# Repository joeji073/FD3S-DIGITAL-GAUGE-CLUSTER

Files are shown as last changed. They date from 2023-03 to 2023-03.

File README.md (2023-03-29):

# FD3S-DIGITAL-GAUGE-CLUSTER

Overview:
I originally started this digital gauge cluster project for my FD3S RX7 since I needed a way of keeping an eye on engine vitals, but didn't want to add gauges pods all over the dashboard. The project actually started as a single external LCD project but eventually turned into a full custom gauge cluster that tried to keep the OEM design language. 

While I'm happy where the gauge cluster currently is, there are still a lot of things that need to be finished. I taught myself how to code by watching Youtube videos and searching the internet so I don't have enough skill and knowledge to finish this. I don't want this project to be wasted and I think with the help of more knowledgeable people, this gauge cluster could become something really nice. 

With that said, I don't want to see this project commercialized or sold for profit. I would like to keep this gauge cluster project free for anyone who would like to make one of their own.

Notes:
1. For those that are expecting to download the files, buy the parts and put it together in a day, it's not even close. Almost all of the parts I used are obsolete and I don't want to spend the time to find alternate solutions.
2. Keep in mind that I've never taken a class on coding/PCB design. What you're going to see is ugly but it works as a proof of concept. I did the work of proving that yes, it's physically possible to fit five LCD screens behind the bezel. The code is literally consists of basic functions that a 10 year old could probably re-write better in a few hours. I uploaded the files not as a way for people to replicate the same thing I have but instead to spark new ideas, whether it's with different hardware or software. I've looked into the LVGL library and it looks like a better option than the FTDI EVE based displays.
3. I'm not going to provide the gauge background jpeg's since they aren't hard to replicate and I'd like to see original designs.

BOM:
1. 3X New Haven Display 3.5" LCD ---- NHD-3.5-320240FT-CSXN-CTP ---- obsolete
2. 2X New Haven Display 7.0" ---- NHD-7.0-800480FT-CSXN-CTP ---- obsolete
3. 5X Teensy 3.5 ---- out of stock, not recommended for new designs

Helpful Links:

https://github.com/FT81xMania/GD23ZUTX

https://excamera.com/files/gd2book_v0.pdf

https://www.ftdichip.com/old2020/Products/Modules/EVE2Modules.html

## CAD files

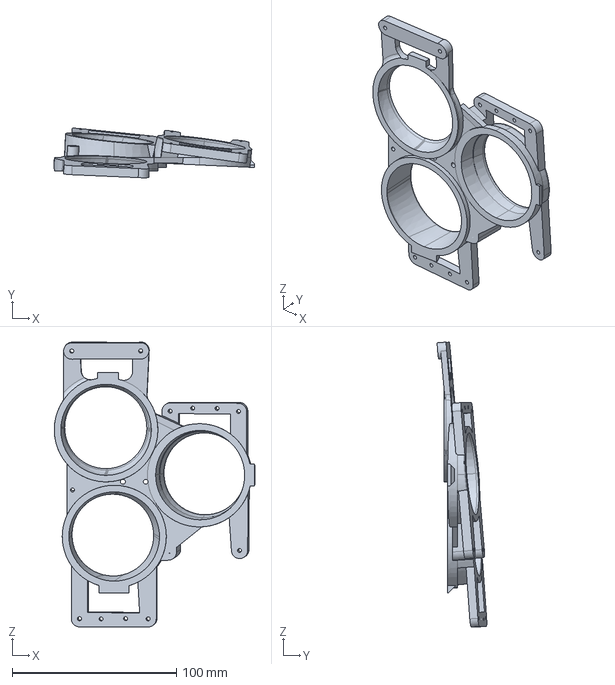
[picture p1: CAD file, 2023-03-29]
triple_gauge.stp
122.1 x 30.2 x 173.5 mm

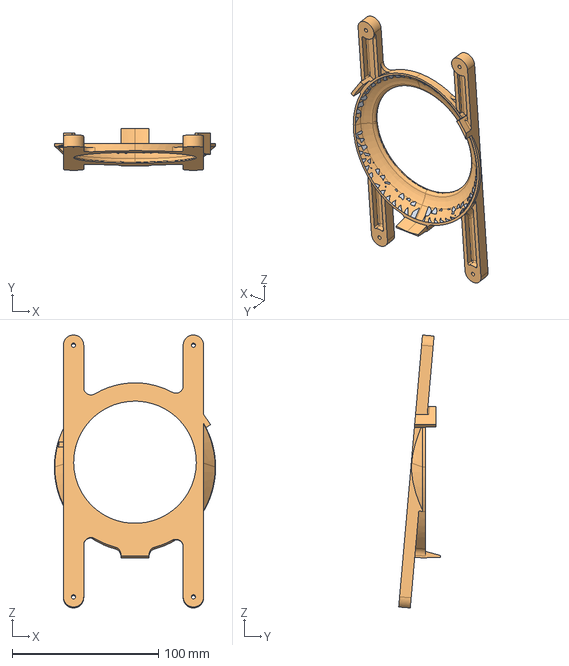
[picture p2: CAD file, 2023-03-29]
center_gauge.stp
110.5 x 28.5 x 187.0 mm

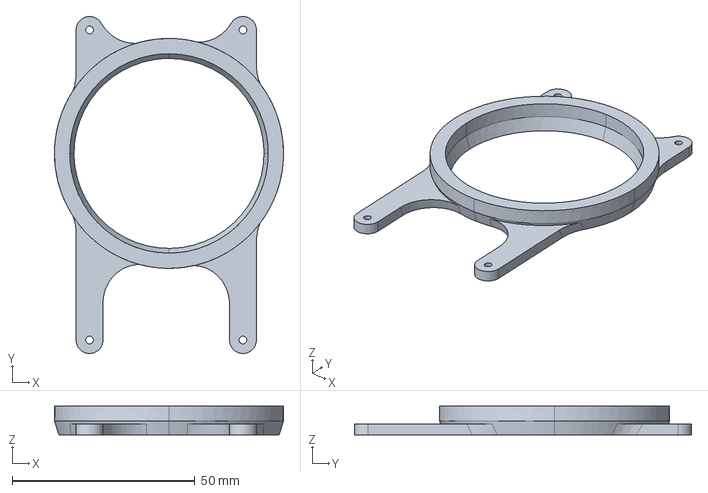
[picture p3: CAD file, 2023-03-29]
bottom_right_gauge.stp
62.7 x 92.3 x 7.82 mm

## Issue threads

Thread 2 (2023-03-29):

Speed signal

joeji073, 2023-03-29:
The speed sensor signal comes from the transmission to the OEM gauge cluster, get's converted to a digital signal then outputs to the ECU. I worked around that issue by removing the speedo from the cluster and soldering wires to the appropriate pins. The speedometer unit is currently sitting behind the dash.

It would be ideal to use one of the Teensy to convert the signal to make it less complicated.

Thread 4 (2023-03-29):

LCD Mounting

joeji073, 2023-03-29:
The LCD brackets I uploaded are preliminary, mainly used to confirm that the LCD's can physically fit behind the bezel. Although I ended up using them how they are, I had to epoxy them onto the bezel which isn't ideal.

I eventually wanted to have it where they would be attached using the stock mounting locations. This was difficult without a 3D scan of the bezel since I had to eyeball everything.

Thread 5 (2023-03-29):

Fuel Level

joeji073, 2023-03-29:
I thought I had the fuel level wiring and code working correctly, but that wasn't the case after installation.

I believe it might be due to how I have the schematic setup but I haven't dug into it.

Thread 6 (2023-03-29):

Odometer

joeji073, 2023-03-29:
I came up with a way of getting odometer data from speed and time. I'm not sure if it's correct but my ECU only outputs speed through CAN and not pulses per mile.

I tried to write code to save the odometer data to memory but I'm missing something since it resets at power off. I'm sure it's something simple but I gave up after a while.

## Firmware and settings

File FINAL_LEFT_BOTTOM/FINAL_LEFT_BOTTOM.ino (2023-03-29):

#include <GD23ZUTX.h>
#include <SPI.h>
#include <IFCT.h>
#include <AnalogSmooth.h>
#include "leftasset.h"
#include <TeensyThreads.h>
#include <EEPROM.h>
#include <EasyButton.h>

#include "I2CTransfer.h"

I2CTransfer myTransfer;

struct STRUCT {
      uint8_t CTPS, CBARO, CAFR, CMAT, CCLT, CBATT, CEGOCOR, CTOTCOR, 
      COILTEMP, CCOOLPRESS, COILP, CFUELP, CETHL, CMPG, CFUELTEMP, CIGNADV, CGEAR, CVSS, CTRAC, CAFRTAR;
      uint16_t CRPM, CKPA;
} canData;

/////////////////////////////////////////////////////////////////// Callbacks
void hi()
{
  myTransfer.rxObj(canData);
  Serial.println(canData.CTPS);
  //Serial.println(testStruct.y);
}

// supplied as a reference - persistent allocation required
const functionPtr callbackArr[] = { hi };
///////////////////////////////////////////////////////////////////

static CAN_message_t rxmsg;

int MAT,BOOST,CLT,VSS,ETHL,OILP,OILT,FUELP,FUELT,BATT,
    COOLP,EGO,TOTCOR,BOOSTTAR,AFR,BARO,TPS,MPG,STATUS,RPM;

int GREY = 0x242424;
int BLACK = 0x000000;
int WHITE = 0xFFE6B5;
int RED = 0xFC3909;

//const int backLight = 37;     //Probably don't need...it's used on the Center display to control backlight
const int buttonPin = 33;     //Action button
const int buttonPin2 = 17;    //Reset button pin
const int headlightPin = 34;    //Dims backlight when headlights are turned on
//const int poten = 38;         //Not connected anymore, deleted when final   

//float TPS;        //used during testing, delete after
//float CTPS;

//float BARO, MAT, CLT, BATT, EGOCOR, TOTCOR, OILTEMP, FUELP, BOOSTTAR, ETHL, MPG, FUELTEMP, COOLPRESS, OILP, STATUS;
//float CBARO, CMAT, CCLT, CBATT, CEGOCOR, CTOTCOR, COILTEMP, CFUELP, CBOOSTTAR, CETHL, CMPG, CFUELTEMP, CCOOLPRESS, COILP;

int screenTrack = 0;
int pageTrack = 0;

int buttonstate;
int lastbuttonstate = LOW;
long lastDebounceTime = 0;  // the last time the output pin was toggled
long debounceDelay = 250;    // the debounce time; increase if the output flickers
unsigned long previousMillis = 0;

EasyButton button(buttonPin);
EasyButton button2(buttonPin2);


//////////////////////////////////////////////////////////////////////////////////////////////

void setup() {

  //pinMode(backLight, OUTPUT);        //Can delete, this is used on Center gauge to control backlight
  //digitalWrite(backLight, LOW);

  //Can0.setBaudRate(500000);

  Serial.begin(9600);

  Wire.begin(0);
  ///////////////////////////////////////////////////////////////// Config Parameters
  configST myConfig;
  myConfig.debug        = true;
  myConfig.callbacks    = callbackArr;
  myConfig.callbacksLen = sizeof(callbackArr) / sizeof(functionPtr);
  /////////////////////////////////////////////////////////////////
  
  myTransfer.begin(Wire, myConfig);

  button.begin();
  button.onPressedFor(1000, onPressedForDuration);
  button.onPressed(onPressed);

  GD.begin();
  LOAD_ASSETS();

  pinMode(headlightPin, INPUT);      

  headlightDim();   //read if headlight is already on 

  LOAD_ASSETS();

  GD.Clear();
  GD.BitmapHandle(3);
  GD.cmd_loadimage(ASSETS_END, 0);
  GD.load("a.jpg");

  delay(5300);    //change this delay to match the main gauge so the needles turn on at the same time

}

///////////////////////////////////////////////////////////////////////////////////////////////

void loop() {

while(screenTrack == 0) {
    headlightDim();
    ////canData();
    reading();


      GD.Clear();
      GD.Begin(BITMAPS);
      GD.Vertex2ii(3,12,3);
      GD.ColorRGB(RED);
      GD.cmd_gauge(118,125,130,12544,9,5,1170,1000);

      GD.ColorRGB(WHITE);
      GD.Begin(BITMAPS);
      GD.Vertex2ii((118-18), (125-18), 2);   // Needle center asset, the 2 might need to change

      GD.swap();
      GD.finish();

      delay(1000);

      sequence();
   
  }

  //////////////////////////////////////////////////////////////////////////////////////////////////////////

while(screenTrack == 1) {           //Analog Fuel pressure gauge

  //canData();
  reading();
  headlightDim();


  GD.Clear();

  button.read();

  GD.Begin(BITMAPS);
  GD.Vertex2ii(3,12,3);  //Will need to add image handle once assets are loaded (x,y,image handle)

  GD.ColorRGB(RED);
  GD.cmd_gauge(118,125,130,12544,9,5,(map(canData.CFUELP, 0, 120,1170, 2170)),1000); //fuel pressure gauge needle

  GD.ColorRGB(WHITE);
  GD.Begin(BITMAPS);
  GD.Vertex2ii((118-18), (125-18), 2);   // Needle center asset, the 2 might need to change


  GD.ColorRGB(WHITE);
  GD.printNfloat(190, 138, canData.CFUELP, 0, NUMBERFONT_HANDLE); //fuel pressure number
  
  GD.swap();
  GD.finish();


}

while(screenTrack == 100) {           //Digital fuel pressure

  //canData();
  reading();
  headlightDim();

  GD.Clear();

  button.read();

  GD.Begin(BITMAPS);
  GD.Vertex2ii(3,12,3);  //Will need to add image handle once assets are loaded (x,y,image handle)

  GD.ColorRGB(WHITE);
  GD.cmd_number(110, 150, 1, OPT_CENTER, canData.CFUELP);

  GD.swap();
  GD.finish();

  }



////////////////////////////////////////////////////////////////////////////////////////////////////////////////////

while(screenTrack == 2) {           //Analog Fuel Temp gauge

  //canData();
  reading();
  headlightDim();

  int GFUELT = canData.CFUELTEMP;

    if (GFUELT < 40) {
      GFUELT = 40;
    }

  GD.Clear();

  button.read();

  GD.Begin(BITMAPS);
  GD.Vertex2ii(3,12,3);  //Will need to add image handle once assets are loaded (x,y,image handle)

  GD.ColorRGB(RED);
  GD.cmd_gauge(118,125,130,12544,9,5,(map(GFUELT, 40, 160,1170, 2170)),1000); //main gauge needle

  GD.ColorRGB(WHITE);
  GD.Begin(BITMAPS);
  GD.Vertex2ii((118-18), (125-18), 2);   // Needle center asset, the 2 might need to change

  GD.ColorRGB(WHITE);
  GD.printNfloat(190, 140, canData.CFUELTEMP, 0, 0); //Speedo numbers

  GD.swap();
  GD.finish();
}

  while(screenTrack == 200) {           //Digital Fuel Temp gauge

  //canData();
  reading();
  headlightDim();

  GD.Clear();

  button.read();

  GD.Begin(BITMAPS);
  GD.Vertex2ii(3,12,3);  //Will need to add image handle once assets are loaded (x,y,image handle)

  GD.ColorRGB(WHITE);
  GD.cmd_number(110, 150, 1, OPT_CENTER, canData.CFUELTEMP);

  GD.swap();
  GD.finish();

 

}

////////////////////////////////////////////////////////////////////////////////////////////////////////////////////

while(screenTrack == 3) {           //Analog Oil Temp Gauge

  //canData();
  reading();
  headlightDim();

  int GOILT = canData.COILTEMP;

    if (GOILT < 100) {
      GOILT = 100;
    }

  GD.Clear();

  button.read();

  GD.Begin(BITMAPS);
  GD.Vertex2ii(3,12,3);  //Will need to add image handle once assets are loaded (x,y,image handle)

  GD.ColorRGB(RED);
  GD.cmd_gauge(118,125,130,12544,9,5,(map(GOILT, 100, 220,1170, 2170)),1000); //main gauge needle

      GD.ColorRGB(WHITE);
      GD.Begin(BITMAPS);
      GD.Vertex2ii((118-18), (125-18), 2);   // Needle center asset, the 2 might need to change


  GD.ColorRGB(WHITE);
  GD.printNfloat(190, 140, canData.COILTEMP, 0, 0); //Speedo numbers

  GD.swap();
  GD.finish();

  }

  while(screenTrack == 300) {           //Digital Oil Temp Gauge

  //canData();
  reading();
  headlightDim();

  GD.Clear();

  button.read();

  GD.Begin(BITMAPS);
  GD.Vertex2ii(3,12,3);  //Will need to add image handle once assets are loaded (x,y,image handle)

  GD.ColorRGB(WHITE);
  GD.cmd_number(110, 150, 1, OPT_CENTER, canData.COILTEMP);

  GD.swap();
  GD.finish();

  }



////////////////////////////////////////////////////////////////////////////////////////////////////////////////////

while(screenTrack == 4) {           //Analog Air temp gauge

  //canData();
  reading();
  headlightDim();

  int GMAT = canData.CMAT;

    if (GMAT < 60){
      GMAT = 60;
    }

  GD.Clear();

  button.read();

  GD.Begin(BITMAPS);
  GD.Vertex2ii(3,12,3);  //Will need to add image handle once assets are loaded (x,y,image handle)

  GD.ColorRGB(RED);
  GD.cmd_gauge(118,125,130,12544,9,5,(map(GMAT, 60, 180,1170, 2170)),1000); //main gauge needle

      GD.ColorRGB(WHITE);
      GD.Begin(BITMAPS);
      GD.Vertex2ii((118-18), (125-18), 2);   // Needle center asset, the 2 might need to change


  GD.ColorRGB(WHITE);
  GD.printNfloat(190, 140, canData.CMAT, 0, 0); //Speedo numbers

  GD.swap();
  GD.finish();

  }

  while(screenTrack == 400) {           //Digital Air Temp Gauge

  //canData();
  reading();
  headlightDim();

  GD.Clear();

  button.read();

  GD.Begin(BITMAPS);
  GD.Vertex2ii(3,12,3);  //Will need to add image handle once assets are loaded (x,y,image handle)

  GD.ColorRGB(WHITE);
  GD.cmd_number(110, 150, 1, OPT_CENTER, canData.CMAT);
  
  GD.swap();
  GD.finish();

  }



////////////////////////////////////////////////////////////////////////////////////////////////////////////////////

while(screenTrack == 5) {           //Digital Ethanol Content Gauge

  //canData();
  reading();
  headlightDim();

  GD.Clear();

  button.read();

  GD.Begin(BITMAPS);
  GD.Vertex2ii(3,12,3);  //Will need to add image handle once assets are loaded (x,y,image handle)

  GD.ColorRGB(WHITE);
  GD.cmd_number(110, 150, 1, OPT_CENTER, canData.CETHL);

  GD.swap();
  GD.finish();

  }



////////////////////////////////////////////////////////////////////////////////////////////////////////////////////

while(screenTrack == 6) {           //Digital Battery Gauge

  //canData();
  reading();
  headlightDim();

  float GBATT = (((float)canData.CBATT)/10.0);
  GD.Clear();

  button.read();

  GD.Begin(BITMAPS);
  GD.Vertex2ii(3,12,3);  //Will need to add image handle once assets are loaded (x,y,image handle)

  GD.ColorRGB(WHITE);
  GD.printNfloat(125, 117, GBATT, 1, 1);

  GD.swap();
  GD.finish();

  }



////////////////////////////////////////////////////////////////////////////////////////////////////////////////////

while(screenTrack == 7) {           //Digital EGO Correction gauge

  //canData();
  reading();
  headlightDim();

  GD.Clear();

  button.read();

  GD.Begin(BITMAPS);
  GD.Vertex2ii(3,12,3);  //Will need to add image handle once assets are loaded (x,y,image handle)

  GD.ColorRGB(WHITE);
  GD.cmd_number(110, 150, 1, OPT_CENTER, canData.CEGOCOR);

  GD.swap();
  GD.finish();

  }



////////////////////////////////////////////////////////////////////////////////////////////////////////////////////

while(screenTrack == 8) {           //Digital Total fuel correction gauge

  //canData();
  reading();
  headlightDim();

  GD.Clear();

  button.read();

  GD.Begin(BITMAPS);
  GD.Vertex2ii(3,12,3);  //Will need to add image handle once assets are loaded (x,y,image handle)

  GD.ColorRGB(WHITE);
  GD.cmd_number(110, 150, 1, OPT_CENTER, canData.CTOTCOR);

  GD.swap();
  GD.finish();

  }



////////////////////////////////////////////////////////////////////////////////////////////////////////////////////

while(screenTrack == 9) {           //Digital Ign Advance

  //canData();
  reading();
  headlightDim();

  GD.Clear();

  button.read();

  GD.Begin(BITMAPS);
  GD.Vertex2ii(3,12,3);  //Will need to add image handle once assets are loaded (x,y,image handle)

  GD.ColorRGB(WHITE);
  GD.cmd_number(110, 150, 1, OPT_CENTER, canData.CIGNADV);

  GD.swap();
  GD.finish();

  }



////////////////////////////////////////////////////////////////////////////////////////////////////////////////////

while(screenTrack == 10) {           //MPG gauge

  //canData();
  reading();
  headlightDim();

  GD.Clear();

  button.read();

   GD.Begin(BITMAPS);
  GD.Vertex2ii(3,12,3);  //Will need to add image handle once assets are loaded (x,y,image handle)


  GD.ColorRGB(WHITE);
  GD.cmd_number(110, 150, 1, OPT_CENTER, canData.CMPG);

  GD.swap();
  GD.finish();

  }

 while(screenTrack == 1000){         //bongo cat easter egg
    

    GD.Clear();

    button.read();  
    GD.BitmapHandle(3);                   //Double check image handle for background jpegs
    GD.cmd_loadimage(ASSETS_END, 0);
    GD.load("BONGO_CAT2.jpg");  
    GD.Begin(BITMAPS);
    GD.Vertex2ii(3,12,3);  

    delay(200);

    GD.swap();

    GD.Clear();
    GD.BitmapHandle(3);                   //Double check image handle for background jpegs
    GD.cmd_loadimage(ASSETS_END, 0);
    GD.load("BONGO_CAT.jpg");  
    GD.Begin(BITMAPS);
    GD.Vertex2ii(3,12,3);  

    delay(200);

    GD.swap();

    GD.finish();

  }

}




////////////////////////////////////////////////////////////////////////////////////////////////////////////////////

void onPressed()
{
  pageTrack = 0;
 // Serial.print("screenTrack = ");
 // Serial.println(screenTrack);
    if (screenTrack == 1){
      GD.Clear();
      GD.BitmapHandle(3);                   //Double check image handle for background jpegs
      GD.cmd_loadimage(ASSETS_END, 0);
      GD.load("4.jpg");                     //Load Fuel Temp BG
      screenTrack++;
      Serial.print("screenTrack = ");
      Serial.println(screenTrack);
      Serial.print("pageTrack = ");
      Serial.println(pageTrack);
    }

    else if (screenTrack == 2){
      GD.Clear();
      GD.BitmapHandle(3);
      GD.cmd_loadimage(ASSETS_END, 0);
      GD.load("5.jpg");                     //Load Oil Temp BG
      screenTrack++;
      Serial.print("screenTrack = ");
      Serial.println(screenTrack);
            Serial.print("pageTrack = ");
      Serial.println(pageTrack);
    }

    else if (screenTrack == 3){
      GD.Clear();
      GD.BitmapHandle(3);
      GD.cmd_loadimage(ASSETS_END, 0);
      GD.load("6.jpg");                       //Air Temp BG
      screenTrack++;
      Serial.print("screenTrack = ");
      Serial.println(screenTrack);
            Serial.print("pageTrack = ");
      Serial.println(pageTrack);
    }

    else if (screenTrack == 4){
      GD.Clear();
      GD.BitmapHandle(3);
      GD.cmd_loadimage(ASSETS_END, 0);
      GD.load("7.jpg");                     //Load Ethanol BG
      screenTrack++;
      Serial.print("screenTrack = ");
      Serial.println(screenTrack);
            Serial.print("pageTrack = ");
      Serial.println(pageTrack);
    }

        else if (screenTrack == 5){
      GD.Clear();
      GD.BitmapHandle(3);
      GD.cmd_loadimage(ASSETS_END, 0);
      GD.load("8.jpg");                       //Load Battery BG
      screenTrack++;
      Serial.print("screenTrack = ");
      Serial.println(screenTrack);
            Serial.print("pageTrack = ");
      Serial.println(pageTrack);
    }

    else if (screenTrack == 6){
      GD.Clear();
      GD.BitmapHandle(3);
      GD.cmd_loadimage(ASSETS_END, 0);
      GD.load("9.jpg");                             //Load EGO Corr BG
      screenTrack++;
      Serial.print("screenTrack = ");
      Serial.println(screenTrack);
            Serial.print("pageTrack = ");
      Serial.println(pageTrack);
    }    

    else if (screenTrack == 7){
      GD.Clear();
      GD.BitmapHandle(3);
      GD.cmd_loadimage(ASSETS_END, 0);
      GD.load("10.jpg");                              //Load Total Fuel Corr BG
      screenTrack++;
      Serial.print("screenTrack = ");
      Serial.println(screenTrack);
            Serial.print("pageTrack = ");
      Serial.println(pageTrack);
    }    

    else if (screenTrack == 8){
      GD.Clear();
      GD.BitmapHandle(3);
      GD.cmd_loadimage(ASSETS_END, 0);
      GD.load("11.jpg");                            //Load Boost target BG
      screenTrack++;
      Serial.print("screenTrack = ");
      Serial.println(screenTrack);
            Serial.print("pageTrack = ");
      Serial.println(pageTrack);
    }    

    else if (screenTrack == 9){
      GD.Clear();
      GD.BitmapHandle(3);
      GD.cmd_loadimage(ASSETS_END, 0);
      GD.load("12.jpg");                            //Load MPG BG
      screenTrack++;
      Serial.print("screenTrack = ");
      Serial.println(screenTrack);
            Serial.print("pageTrack = ");
      Serial.println(pageTrack);
    }    

    else if (screenTrack == 10){
      GD.Clear();
      GD.BitmapHandle(3);
      GD.cmd_loadimage(ASSETS_END, 0);
      GD.load("3.jpg");                           //Return back to coolant temp BG
      screenTrack = 1;
      Serial.print("screenTrack = ");
      Serial.println(screenTrack);
            Serial.print("pageTrack = ");
      Serial.println(pageTrack);
    }    

    else if (screenTrack == 100){
      GD.Clear();
      GD.BitmapHandle(3);
      GD.cmd_loadimage(ASSETS_END, 0);
      GD.load("4.jpg");                           //Return back to coolant temp BG
      screenTrack = 2;
      Serial.print("screenTrack = ");
      Serial.println(screenTrack);
            Serial.print("pageTrack = ");
      Serial.println(pageTrack);
    }    

    else if (screenTrack == 200){
      GD.Clear();
      GD.BitmapHandle(3);
      GD.cmd_loadimage(ASSETS_END, 0);
      GD.load("5.jpg");                           //Return back to coolant temp BG
      screenTrack = 3;
      Serial.print("screenTrack = ");
      Serial.println(screenTrack);
            Serial.print("pageTrack = ");
      Serial.println(pageTrack);
    }   

    else if (screenTrack == 300){
      GD.Clear();
      GD.BitmapHandle(3);
      GD.cmd_loadimage(ASSETS_END, 0);
      GD.load("6.jpg");                           //Return back to coolant temp BG
      screenTrack = 4;
      Serial.print("screenTrack = ");
      Serial.println(screenTrack);
            Serial.print("pageTrack = ");
      Serial.println(pageTrack);
    } 

    else if (screenTrack == 400){
      GD.Clear();
      GD.BitmapHandle(3);
      GD.cmd_loadimage(ASSETS_END, 0);
      GD.load("7.jpg");                           //Return back to coolant temp BG
      screenTrack = 5;
      Serial.print("screenTrack = ");
      Serial.println(screenTrack);
            Serial.print("pageTrack = ");
      Serial.println(pageTrack);
    }  

    else if (screenTrack == 1000){
      GD.Clear();
      GD.BitmapHandle(3);
      GD.cmd_loadimage(ASSETS_END, 0);
      GD.load("3.jpg");                           //Return back to coolant temp BG
      screenTrack = 1;
      Serial.print("screenTrack = ");
      Serial.println(screenTrack);
            Serial.print("pageTrack = ");
      Serial.println(pageTrack);
    }   
}

void onPressedForDuration()
{
   
  if (screenTrack == 1){
    GD.Clear();
    GD.BitmapHandle(3);
    GD.cmd_loadimage(ASSETS_END, 0);
    GD.load("3a.jpg");
    screenTrack = 100;  
    }

  else if (screenTrack == 100){
    GD.Clear();
    GD.BitmapHandle(3);
    GD.cmd_loadimage(ASSETS_END, 0);
    GD.load("3.jpg");
    screenTrack = 1;  
    }

  else if (screenTrack == 2){
    GD.Clear();
    GD.BitmapHandle(3);
    GD.cmd_loadimage(ASSETS_END, 0);
    GD.load("4a.jpg");    
    screenTrack = 200;  
    }

  else if (screenTrack == 200){
    GD.Clear();
    GD.BitmapHandle(3);
    GD.cmd_loadimage(ASSETS_END, 0);
    GD.load("4.jpg");    
    screenTrack = 2;  
    }

  else if (screenTrack == 3){
    GD.Clear();
    GD.BitmapHandle(3);
    GD.cmd_loadimage(ASSETS_END, 0);
    GD.load("5a.jpg");    
    screenTrack = 300;  
    }

  else if (screenTrack == 300){
    GD.Clear();
    GD.BitmapHandle(3);
    GD.cmd_loadimage(ASSETS_END, 0);
    GD.load("5.jpg");    
    screenTrack = 3;  
    }

  else if (screenTrack == 4){
    GD.Clear();
    GD.BitmapHandle(3);
    GD.cmd_loadimage(ASSETS_END, 0);
    GD.load("6a.jpg");    
    screenTrack = 400;  
    }

  else if (screenTrack == 400){
    GD.Clear();
    GD.BitmapHandle(3);
    GD.cmd_loadimage(ASSETS_END, 0);
    GD.load("6.jpg");    
    screenTrack = 4;  
    }

  else if (screenTrack == 10){
   // GD.Clear();
  //  GD.BitmapHandle(3);
  //  GD.cmd_loadimage(ASSETS_END, 0);
  //  GD.load("BONGO_CAT.jpg");    
    screenTrack = 1000;  
    }

  else if (screenTrack == 1000){
    GD.Clear();
    GD.BitmapHandle(3);
    GD.cmd_loadimage(ASSETS_END, 0);
    GD.load("12.jpg");    
    screenTrack = 10;  
    }
  
  Serial.print("pageTrack = ");
  Serial.println(pageTrack);
}

/////////////////////////////////////////////////////////////////////////////////////////////////////////
      /*
void canData() {

  if ( Can0.read(rxmsg) ) {
    switch (rxmsg.id) { // Using IDs from 1512 as Megasquirt CAN broadcast frames for Simplified Dash Broadcasting.
      // EAch frame represents a data group http://www.msextra.com/doc/pdf/Megasquirt_CAN_Broadcast.pdf
      case 1521:
        STATUS = (float)(word(rxmsg.buf[3],rxmsg.buf[3]));  // Status of engine state
      break;
      case 1522:
        CBARO = (float)(word(rxmsg.buf[0], rxmsg.buf[1]));  //divide by 10
        CMAT = (float)(word(rxmsg.buf[4], rxmsg.buf[5]));  //divide by 10
        CCLT = (float)(word(rxmsg.buf[6], rxmsg.buf[7]));  //divide by 10
      break;
      case 1523:
        CTPS = (float)(word(rxmsg.buf[0], rxmsg.buf[1]));  //divide by 10
        CBATT = (float)(word(rxmsg.buf[2], rxmsg.buf[3]));  //divide by 10
      break;
      case 1524:
        CEGOCOR = (float)(word(rxmsg.buf[2], rxmsg.buf[3]));  //divide by 10
      break;
      case 1526:
        CTOTCOR = (float)(word(rxmsg.buf[0], rxmsg.buf[1]));  //divide by 10
      break;
      case 1533:
        COILTEMP = (float)(word(rxmsg.buf[4], rxmsg.buf[5]));  //divide by 10
        CCOOLPRESS = (float)(word(rxmsg.buf[6], rxmsg.buf[7]));  //divide by 10
      break;
      case 1535:
        COILP = (float)(word(rxmsg.buf[0], rxmsg.buf[1]));  //divide by 10
        CFUELP = (float)(word(rxmsg.buf[2], rxmsg.buf[3]));  //divide by 10
      break;
      case 1537:
        CBOOSTTAR = (float)(word(rxmsg.buf[0], rxmsg.buf[1]));  //divide by 10
      break;
      case 1567:
        CETHL = (float)(word(rxmsg.buf[0], rxmsg.buf[1]));  //divide by 10
      break;
      case 1572:
        CMPG = (float)(word(rxmsg.buf[6], rxmsg.buf[7]));  //divide by 10, units is l/km
      break;
      case 1573:
        CFUELTEMP = (float)(word(rxmsg.buf[4], rxmsg.buf[5]));  //divide by 10
      break;
    }
}
}
*/



////////////////////////////////////////////////////////////////////////////////////////////////////////////////////
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

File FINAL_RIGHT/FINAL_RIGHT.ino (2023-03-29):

#include <GD23ZUTX.h>
#include <SPI.h>
#include <IFCT.h>
#include <AnalogSmooth.h>
#include "rightassets.h"
#include <TeensyThreads.h>
#include <EEPROM.h>
#include <EasyButton.h>
#include "FastLED.h"
#include "I2CTransfer.h"

I2CTransfer myTransfer;

struct STRUCT {
      uint8_t CTPS, CBARO, CAFR, CMAT, CCLT, CBATT, CEGOCOR, CTOTCOR, 
      COILTEMP, CCOOLPRESS, COILP, CFUELP, CETHL, CMPG, CFUELTEMP, CIGNADV, CGEAR, CVSS, CTRAC, CAFRTAR;
      uint16_t CRPM, CKPA;
} canData;

/////////////////////////////////////////////////////////////////// Callbacks
void hi()
{
  myTransfer.rxObj(canData);
 
  //Serial.println(testStruct.y);
}

// supplied as a reference - persistent allocation required
const functionPtr callbackArr[] = { hi };
///////////////////////////////////////////////////////////////////

//int MAT,BOOST,CLT,VSS,ETHL,OILP,OILT,FUELP,FUELT,BATT,
//    COOLP,EGO,TOTCOR,BOOSTTAR,AFR,BARO,TPS,MPG,STATUS,RPM;

uint32_t startFPS=0, endFPS=0, drawT=0;   //used for loops/sec counter

const int SHTLED = 36;
const int buttonPin = 33;  
const int buttonPin2 = 17; 
const int headlightPin = 34;
const int wire = 32;
const int poten = 38;
//const int CANafr = 22;
//const int CANboost = 23;
const int seatbeltPin = 15;
const int brakelightPin = 39;
//const int highbeamPin = 18;

int shiftlightVal = 7500;
int cltlightVal = 205;
int matlightVal = 180;

int GREY = 0x242424;
int BLCK = 0x000000;

int screenTrack = 0;
int pageTrack = 0;

float PSI; 
float peakBoost = 0;

float val, GAFR;

int seatbeltLight, brakeLight, highbeamLight, lowgasLight;

EasyButton button(buttonPin);
EasyButton button2(buttonPin2);

//int buttonstate;
//int lastbuttonstate = LOW;
//long lastDebounceTime = 0;  // the last time the output pin was toggled
//long debounceDelay = 250;    // the debounce time; increase if the output flickers
//unsigned long previousMillis = 0;

//////////////////////////////////////////////////////////////////////////////////////////////////////////////

#define NUM_LEDS 1
#define DATA_PIN 29
CRGB leds[NUM_LEDS];

unsigned long RedledpreviousMillis = 0; 
const long Redledinterval = 125;           // interval at which to blink (milliseconds)
bool RedledState = false;

unsigned long OrgledpreviousMillis = 0; 
const long Orgledinterval = 500;           // interval at which to blink (milliseconds)
bool OrgledState = false;

//////////////////////////////////////////////////////////////////////////////////////////////////////////////


void setup() {

 // Can0.setBaudRate(500000);
//  CAN_filter_t allPassFilter;
//  allPassFilter.id=0;
//  allPassFilter.ext=1;
//  allPassFilter.rtr=0;
//    for (uint8_t filterNum = 4; filterNum < 16;filterNum++)
 //     {
 //       CANbus.setFilter(allPassFilter,filterNum); 
 //     }

   Wire.begin(0);
  ///////////////////////////////////////////////////////////////// Config Parameters
  configST myConfig;
  myConfig.debug        = true;
  myConfig.callbacks    = callbackArr;
  myConfig.callbacksLen = sizeof(callbackArr) / sizeof(functionPtr);
  /////////////////////////////////////////////////////////////////
  
  myTransfer.begin(Wire, myConfig);

  button.begin();
  button2.begin();
  button.onPressedFor(1000, onPressedForDuration);
  button.onPressed(onPressed);
  button2.onPressedFor(1000, onButton2longPressed);
  button2.onPressed(onButton2Pressed);
  
  FastLED.addLeds<NEOPIXEL, DATA_PIN>(leds, NUM_LEDS);

  GD.begin();
  LOAD_ASSETS();
  
  pinMode(SHTLED, OUTPUT);
 // pinMode(buttonpin, INPUT);
  pinMode(headlightPin, INPUT);
 // pinMode(wire, INPUT_PULLUP);   /////////Remove once final
 // pinMode(poten, INPUT); //////////
 // pinMode(CANafr, INPUT);
 // pinMode(CANboost, INPUT);
  pinMode(seatbeltPin, INPUT);
  pinMode(brakelightPin, INPUT);
  //pinMode(highbeamPin, INPUT);

  headlightDim();

  //shiftlightVal = EEPROM.read(0);
  //cltlightVal = EEPROM.read(4);
  //matlightVal = EEPROM.read(8);
  

  LOAD_ASSETS();

  GD.Clear();
  GD.BitmapHandle(2);
  GD.cmd_loadimage(ASSETS_END, 0);
  GD.load("RIGHTGAUGE11.jpg");

  delay(5400);     //10200ms delay 

}

void loop() {
 
while(screenTrack == 0){  

  reading();
  headlightDim();
  
      //canData();
      GD.Clear();
      GD.Begin(BITMAPS);
      GD.Vertex2ii(0, 0, 2);
      GD.ColorRGB(0xff0000);
      GD.cmd_gauge(158,221,125,12544,9,5,1170,1000); //boost gauge needle
      GD.cmd_gauge(335,388,125,12544,9,5,1170,1000); //afr gauge needle

      GD.ColorRGB(0xFFFFFF);
      GD.Begin(BITMAPS);
      GD.Vertex2ii((158-22), (221-22), 1); // Needle center asset, the -22 is half of the image width
      GD.Vertex2ii((335-22), (388-22), 1); // Needle center asset, the -22 is half of the image width

      GD.swap();
      GD.finish();
     
      delay(1000);

       sequence();
    
}

//////////////////////////////////////////////////////////////////////////////////////////////////////////////

while(screenTrack == 1) {

  GAFR = ((float)canData.CAFR/10.0);
    
    if (GAFR > 19) {
      GAFR = 19;
    }

  headlightDim();
  reading();
  
  button.read();
  button2.read();
  
  GD.Clear();
          
  GD.Begin(BITMAPS);
  GD.Vertex2ii(0, 0, 2);
  
            //High Beam warning light
      GD.Begin(RECTS);          
      GD.ColorRGB(0x000000);
      GD.Vertex2ii(0, 335);
      GD.Vertex2ii(67, 375);

    if (seatbeltLight == HIGH) {             //Seat belt warning light
      GD.Begin(RECTS);          
      GD.ColorRGB(0x000000);
      GD.Vertex2ii(69, 335);
      GD.Vertex2ii(112, 375);
    }


    if (brakeLight == HIGH) {             //Brake warning light
      GD.Begin(RECTS);          
      GD.ColorRGB(0x000000);
      GD.Vertex2ii(115, 330);
      GD.Vertex2ii(160, 380);
    }
  
  GD.ColorRGB(0xff0000);
  GD.cmd_gauge(158,221,125,12544,9,5,(map(canData.CKPA, 0, 306,1170, 2170)),1000); //boost gauge needle
  GD.cmd_gauge(335,388,125,12544,9,5,(map(GAFR, 10, 19,1170, 2170)),1000); //afr gauge needle
  
  GD.ColorRGB(0xFFFFFF);
  
  GD.Begin(BITMAPS);
  GD.Vertex2ii((158-22), (221-22), 1); // Needle center asset, the -22 is half of the image width
  GD.Vertex2ii((335-22), (388-22), 1); // Needle center asset, the -22 is half of the image width

  if (pageTrack == 0){
    GD.ColorRGB(0xfaf9ff);
    GD.printNfloat(380 , 180, PSI, 0, NUMBERFONT_HANDLE); //BOOST numbers
    GD.Begin(RECTS);          
    GD.ColorRGB(0x000000);
    GD.Vertex2ii(355, 248);
    GD.Vertex2ii(410, 280);
    }

  else if (pageTrack == 1){
    GD.ColorRGB(0xFFA500);
    GD.printNfloat(380 , 180, peakBoost, 0, NUMBERFONT_HANDLE); //Peak BOOST numbers
    }
  
  GD.ColorRGB(0xfaf9ff);
  GD.printNfloat(170 , 410, GAFR, 1, NUMBERFONT_HANDLE); //AFR numbers

  //Serial.println(reads);

  GD.swap();
  GD.finish();

  
}

//////////////////////////////////////////////////////////////////////////////////////////////////////////////
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
